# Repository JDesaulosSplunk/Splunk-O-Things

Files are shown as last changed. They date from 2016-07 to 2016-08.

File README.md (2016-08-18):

# Splunk-O-Things
Code, Schematics, and Guides for the Splunk O' Things device

## Setup
Follow GitHub's instructions here for downloading: https://help.github.com/articles/cloning-a-repository/

Add a "config.txt" to the SD card on the device.

## "config.txt"
This file is stored on the SD card on the device in the root directory.   
The four items it needs to have are: 
  1. `Port` number to send data to
  2. `Host` IP or DNS address to send data to
  3. `SSID` of the Wi-Fi network the device will connect to
  4. `Password` associated with the `SSID`

This file is formatted in the same order as above. each item is on a new line with no other formatting text.

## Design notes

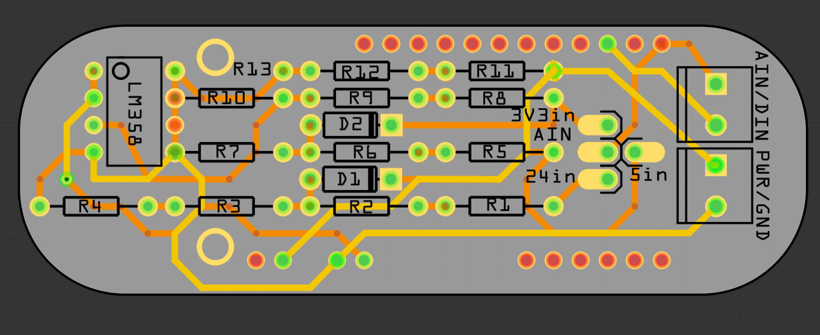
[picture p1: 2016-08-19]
Schematics:Diagrams/PCB Screen Shot.png

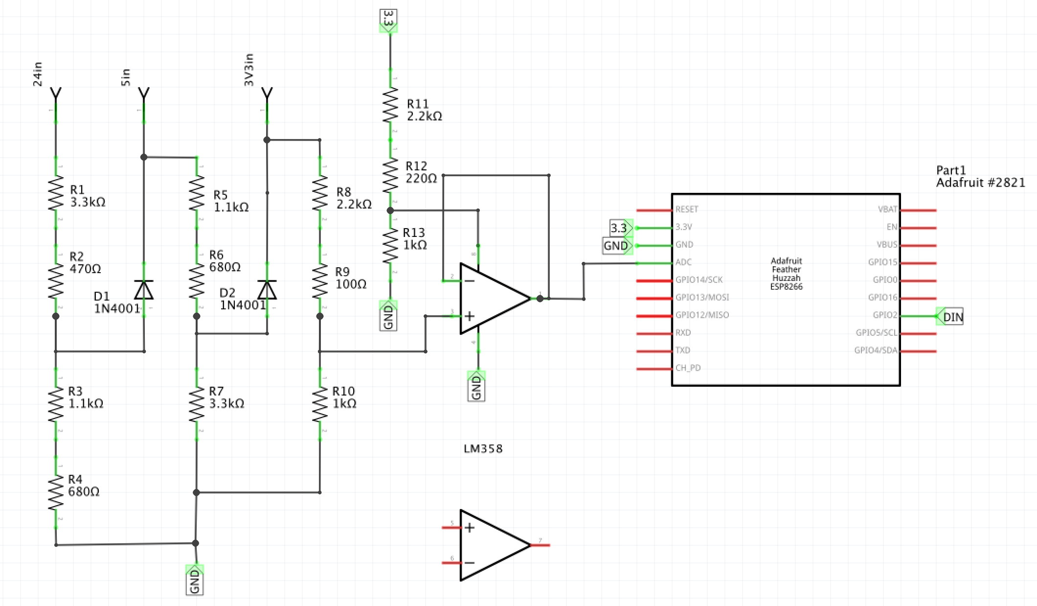
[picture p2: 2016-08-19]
Schematics:Diagrams/Analog Stepdown and Buffering Circuit.png

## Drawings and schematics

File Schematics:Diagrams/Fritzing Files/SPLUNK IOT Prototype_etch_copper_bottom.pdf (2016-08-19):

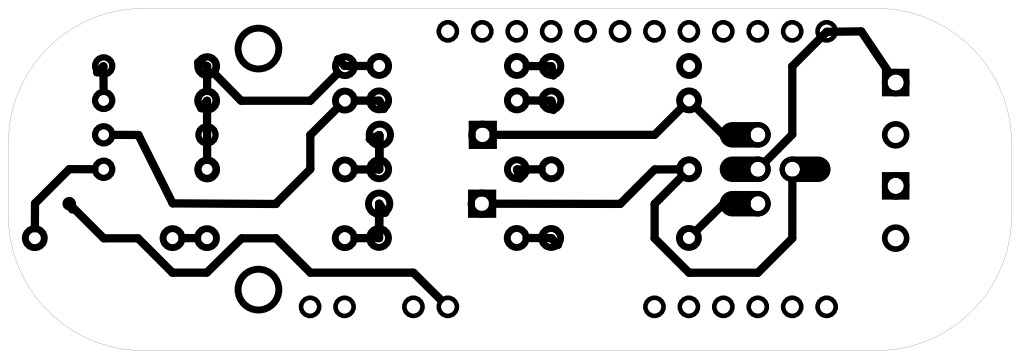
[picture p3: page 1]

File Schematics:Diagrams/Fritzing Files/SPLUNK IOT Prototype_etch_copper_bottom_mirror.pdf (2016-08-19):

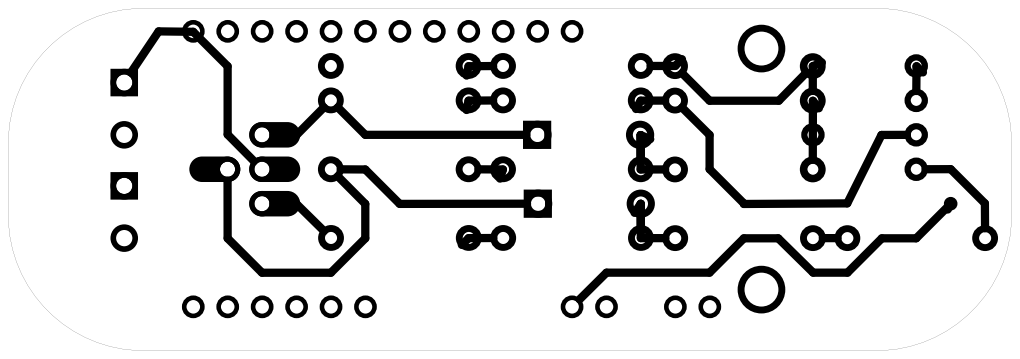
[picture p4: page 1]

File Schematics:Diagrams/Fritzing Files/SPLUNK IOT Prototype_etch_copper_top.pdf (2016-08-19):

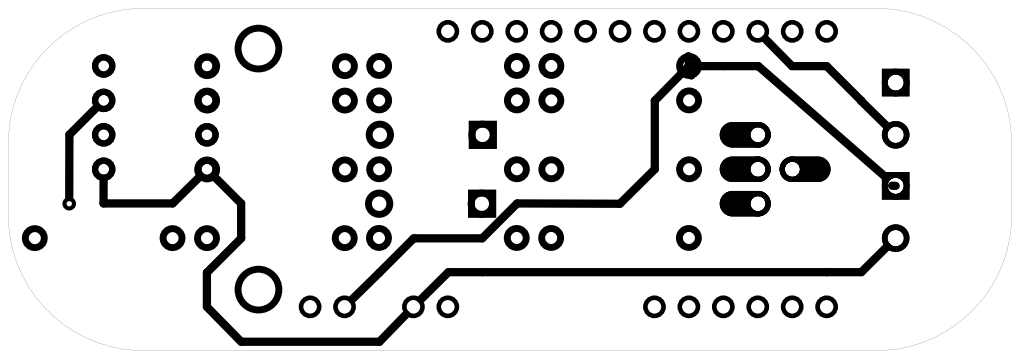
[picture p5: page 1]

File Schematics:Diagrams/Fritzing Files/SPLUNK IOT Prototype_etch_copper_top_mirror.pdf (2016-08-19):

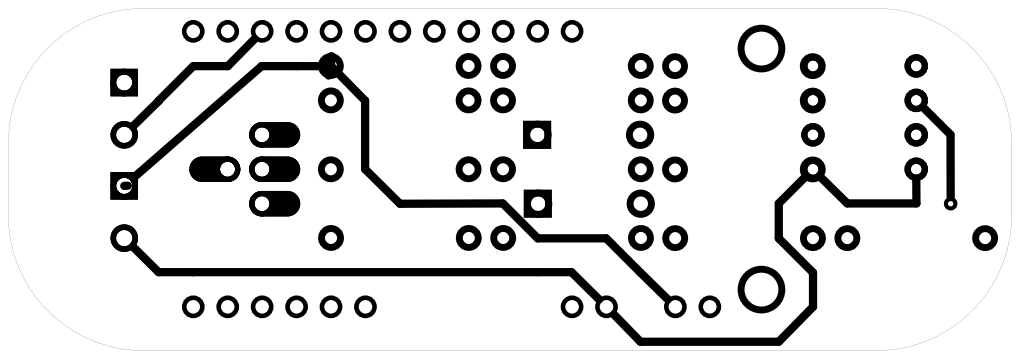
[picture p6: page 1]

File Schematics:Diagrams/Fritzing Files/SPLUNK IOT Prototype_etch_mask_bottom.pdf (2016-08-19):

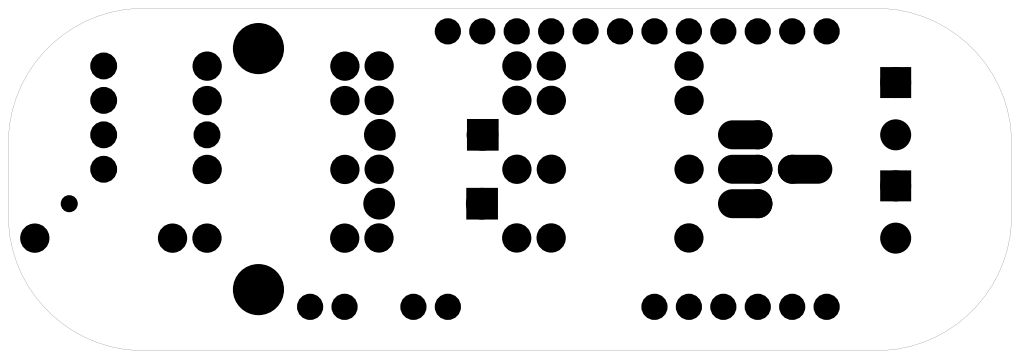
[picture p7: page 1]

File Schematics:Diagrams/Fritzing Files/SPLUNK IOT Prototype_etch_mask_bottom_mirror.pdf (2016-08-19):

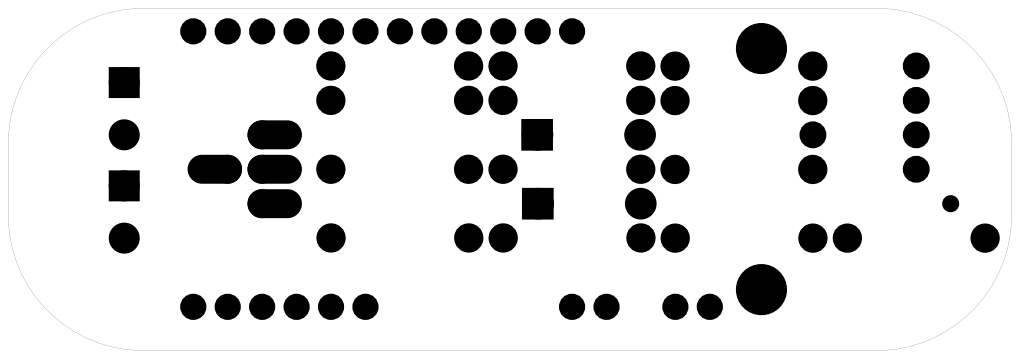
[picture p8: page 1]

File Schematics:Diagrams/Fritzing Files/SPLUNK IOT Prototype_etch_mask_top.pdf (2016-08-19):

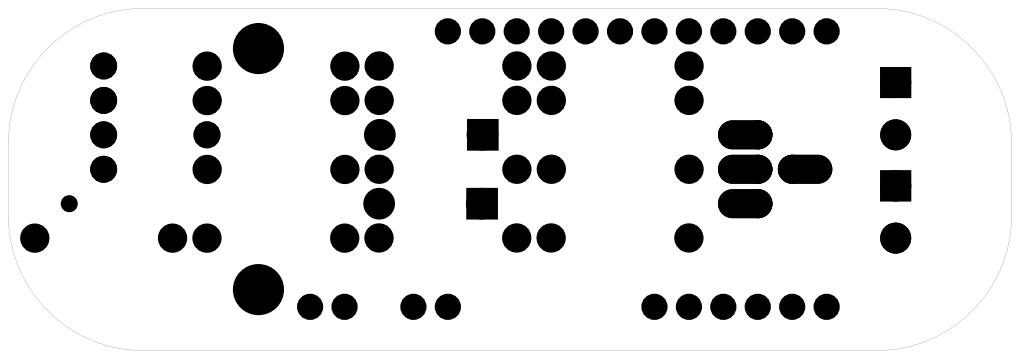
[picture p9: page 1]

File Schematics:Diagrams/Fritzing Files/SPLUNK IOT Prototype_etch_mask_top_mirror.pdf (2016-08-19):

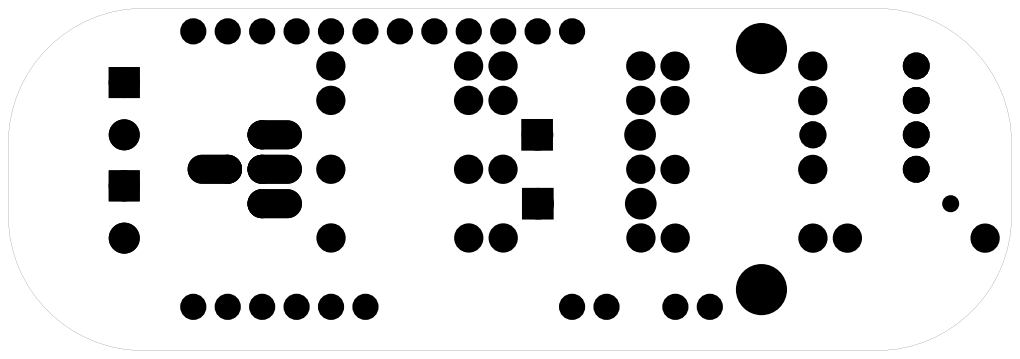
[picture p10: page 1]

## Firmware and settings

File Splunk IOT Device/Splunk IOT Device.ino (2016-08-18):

/* https://github.com/esp8266/Arduino/blob/master/libraries/ESP8266WiFi/examples/WiFiClientBasic/WiFiClientBasic.ino
 *  This sketch sends a message to a TCP server
 *
 */
// Date and time functions using a DS1307 RTC connected via I2C and Wire lib
#include <Wire.h>
#include "RTClib.h"

#if defined(ARDUINO_ARCH_SAMD)
// for Zero, output on USB Serial console, remove line below if using programming port to program the Zero!
	#define Serial SerialUSB
#endif

#include <ESP8266WiFi.h>
#include <ESP8266WiFiMulti.h>
#include "DHT.h"

#include <SPI.h>
#include <SD.h>

#include <WiFiUdp.h>
#define DHTPIN 2
#define DHTTYPE DHT11   // DHT 11
DHT dht(DHTPIN, DHTTYPE);
float f;
float h;
int pR;
char buffer[6];
// Use WiFiClient class to create TCP connections
WiFiClient client;

RTC_PCF8523 rtc;
ESP8266WiFiMulti WiFiMulti;

char daysOfTheWeek[7][12] = {"Sunday", "Monday", "Tuesday", "Wednesday", "Thursday", "Friday", "Saturday"};
TimeSpan offset = 18020;

int photocellPin = 0;     // the cell and 10K pulldown are connected to a0
int photocellReading;     // the analog reading from the sensor divider
const int chipSelect = 15;

unsigned int localPort = 2390;      // local port to listen for UDP packets
IPAddress timeServerIP; // time.nist.gov NTP server address
const char* ntpServerName = "time.nist.gov";

const int NTP_PACKET_SIZE = 48; // NTP time stamp is in the first 48 bytes of the message

byte packetBuffer[ NTP_PACKET_SIZE]; //buffer to hold incoming and outgoing packets

// A UDP instance to let us send and receive packets over UDP
WiFiUDP udp;
const uint16_t port = 2319;
const char * host = "192.168.10.227"; // ip or dns

unsigned long epoch;

String settings[4];

unsigned long sendNTPpacket(IPAddress& address) {
	Serial.println("sending NTP packet...");
	// set all bytes in the buffer to 0
	memset(packetBuffer, 0, NTP_PACKET_SIZE);
	// Initialize values needed to form NTP request
	// (see URL above for details on the packets)
	packetBuffer[0] = 0b11100011;   // LI, Version, Mode
	packetBuffer[1] = 0;     // Stratum, or type of clock
	packetBuffer[2] = 6;     // Polling Interval
	packetBuffer[3] = 0xEC;  // Peer Clock Precision
	// 8 bytes of zero for Root Delay & Root Dispersion
	packetBuffer[12]  = 49;
	packetBuffer[13]  = 0x4E;
	packetBuffer[14]  = 49;
	packetBuffer[15]  = 52;

	// all NTP fields have been given values, now
	// you can send a packet requesting a timestamp:
	udp.beginPacket(address, 123); //NTP requests are to port 123
	udp.write(packetBuffer, NTP_PACKET_SIZE);
	udp.endPacket();
}

void doUDP() {
	Serial.println("Starting UDP");
	udp.begin(localPort);
	Serial.print("Local port: ");
	Serial.println(udp.localPort());

	WiFi.hostByName(ntpServerName, timeServerIP);
	sendNTPpacket(timeServerIP); // send an NTP packet to a time server
	// wait to see if a reply is available
	delay(1000);

	int cb = udp.parsePacket();
	if (!cb)
	{
		Serial.println("no packet yet");
	}
	else
	{
		Serial.print("packet received, length=");
		Serial.println(cb);
		// We've received a packet, read the data from it
		udp.read(packetBuffer, NTP_PACKET_SIZE); // read the packet into the buffer

		//the timestamp starts at byte 40 of the received packet and is four bytes,
		// or two words, long. First, esxtract the two words:

		unsigned long highWord = word(packetBuffer[40], packetBuffer[41]);
		unsigned long lowWord = word(packetBuffer[42], packetBuffer[43]);
		// combine the four bytes (two words) into a long integer
		// this is NTP time (seconds since Jan 1 1900):
		unsigned long secsSince1900 = highWord << 16 | lowWord;
		Serial.print("Seconds since Jan 1 1900 = " );
		Serial.println(secsSince1900);

		// now convert NTP time into everyday time:
		Serial.print("Unix time = ");
		// Unix time starts on Jan 1 1970. In seconds, that's 2208988800:
		const unsigned long seventyYears = 2208988800UL;
		// subtract seventy years:
		epoch = secsSince1900 - seventyYears;
		// print Unix time:
		Serial.println(epoch);
	}
}

void getSettings(char* fileName, String *settings) {
	byte b = 0;
	if (SD.exists(fileName) == false)
	{
		Serial.println("File not found");
		return;
	}
	File myFile = SD.open(fileName, FILE_READ);
	if (!myFile)
	{
		Serial.println("Cannot open file");
		return;
	}
	myFile.seek(0);
	while (myFile.available())
	{
		settings[b] = myFile.readStringUntil('\n');
		b++;
	}
	myFile.close();
	Serial.print("Host: ");
	Serial.println(settings[0]);
	Serial.print("Port: ");
	Serial.println(settings[1]);
	Serial.print("SSID: ");
	Serial.println(settings[2]);
	Serial.print("PASS: ");
	Serial.println(settings[3]);
}

void setup() {
	#ifndef ESP8266
		while (!Serial); // for Leonardo/Micro/Zero
	#endif

	Serial.begin(115200);
	delay(10);

	Serial.print("Initializing SD card...");
	// see if the card is present and can be initialized:
	if (!SD.begin(chipSelect))
	{
		Serial.println("Card failed, or not present");
		// don't do anything more:
		return;
	}
	Serial.println("card initialized.");

//***************	 Gets wifi information from SD card.	***************
	getSettings("config.txt", settings);

	const uint16_t port2 = atoi(settings[1].c_str());
	const char * host2 = settings[0].c_str(); // ip or dns
	const char * mySSID2 = settings[2].c_str();
	const char * PASS2 = settings[3].c_str();

	Serial.println(port2);
	Serial.println(host2);
	Serial.println(mySSID2);
	Serial.println(PASS2);
//******************************************************************

	// We start by connecting to a WiFi network
	WiFiMulti.addAP(mySSID2,PASS2);

	Serial.println();
	Serial.println();
	Serial.print("Wait for WiFi... ");

	while(WiFiMulti.run() != WL_CONNECTED)
	{
		Serial.print(".");
		delay(500);
	}

	Serial.println();
	Serial.println("WiFi connected");
	Serial.println("IP address: ");
	Serial.println(WiFi.localIP());

    delay(500);

	Serial.print("connecting to ");
	Serial.println(host2);

	if (!client.connect(host2, port2))
	{
		Serial.println("connection failed");
		Serial.println("wait 5 sec...");
		delay(5000);
		return;
	}

	doUDP();

	if (! rtc.begin())
	{
		Serial.println("Couldn't find RTC");
	while (1);
	}

	if (! rtc.initialized())
	{
		Serial.println("RTC is NOT running!");
		// following line sets the RTC to the date & time this sketch was compiled
		rtc.adjust(DateTime(epoch));
	}

}

void loop() {
	const uint16_t port2 = atoi(settings[1].c_str());
	const char * host2 = settings[0].c_str(); // ip or dns

	f = dht.readTemperature(true);
	h = dht.readHumidity();
	String tf = dtostrf(f, 4, 1, buffer);
	float hif = dht.computeHeatIndex(f, h);
	pR = analogRead(photocellPin);

	DateTime now = rtc.now();
	String dataString = "{\"Time\":\"" + (String)now.unixtime() + "\",\"Temperature\":\"" + tf + "\",\"Humidity\":\"" + h + "\",\"Light\":\"" + pR + "\",\"Heat_Index\":\"" + hif + "\"}";

//***************	Send dataString over TCP to Splunk/Forwarder	***************
	if (client.connected())
	{
		client.println(dataString);
		Serial.print("Data sent over TCP: ");
		Serial.println(dataString);
	}
	else
	{
		Serial.println("Data NOT SENT OVER TCP!");
		Serial.println("Reconnecting to tcp port" + port2);

		if (!client.connect(host2, port2))
		{
			Serial.println("connection failed");
			Serial.println("wait 5 sec...");
			delay(5000);
			return;
		}
		else
		{
			Serial.println("Reconnected.");
		}
		client.println(dataString);
		Serial.print("Data sent over TCP: ");
		Serial.println(dataString);
	}

//***************	Write dataString to SD card.	***************
	File dataFile = SD.open("datalog.txt", FILE_WRITE);

	// if the file is available, write to it:
	if (dataFile)
	{
		dataFile.println(dataString);
		dataFile.close();
	}
	// if the file isn't open, pop up an error:
	else
	{
		Serial.println("error opening datalog.txt");
	}

	Serial.println("wait 3 sec...");
	delay(3000);
}

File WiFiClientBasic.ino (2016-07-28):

  /*
 *  This sketch sends a message to a TCP server
 *
 */

#include <ESP8266WiFi.h>
#include <ESP8266WiFiMulti.h>

ESP8266WiFiMulti WiFiMulti;
String temp;
void setup() {
    Serial.begin(9600);
    delay(10);

    // We start by connecting to a WiFi network
    WiFiMulti.addAP("SSID", "PASS");

    Serial.println();
    Serial.println();
    Serial.print("Wait for WiFi... ");

    while(WiFiMulti.run() != WL_CONNECTED) {
        Serial.print(".");
        delay(500);
    }

    Serial.println("");
    Serial.println("WiFi connected");
    Serial.println("IP address: ");
    Serial.println(WiFi.localIP());

    delay(500);
}


void loop() {
    const uint16_t port = 2319;
    const char * host = "192.168.10.82"; // ip or dns

    
    
    Serial.print("connecting to ");
    Serial.println(host);

    // Use WiFiClient class to create TCP connections
    WiFiClient client;

    if (!client.connect(host, port)) {
        Serial.println("connection failed");
        Serial.println("wait 5 sec...");
        delay(5000);
        return;
    }
    delay(10000);
    temp = Serial.read();
    delay(1000);
    // This will send the request to the server
    client.print(temp);
    Serial.println("3");
    Serial.println(temp);
    delay(2000);

    //read back one line from server
    String line = client.readStringUntil('\r');
    client.println(line);

    Serial.println("closing connection");
    client.stop();
    
    Serial.println("wait 5 sec...");
    delay(5000);
}

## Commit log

2016-08-04 Arduino Pro Mini Test Code
    Test code for the Arduino Pro Mini for Serial Communications with an
    ESP8266.
2016-08-04 Modification for Adafruit Feather Huzzah
    Code to send temperature data to Splunk from an Adafruit Feather
    Huzzah.
2016-08-04 Working for sending temperature data
2016-08-04 Revert "Make TCP Great Again"
    This reverts commit c1ed67d7162702d13736d6afc592f04e63c47891.
    [WiFiClientBasic.ino]
2016-08-04 Working Code with JSON Formatting addition
    Discovered that the error with unixtime not appearing in Splunk was due
    to the fact that the time was in GMT and not CST. Will need to resolve
    time zone issue
    [WiFiClientBasic.ino]
2016-08-05 Added Time Offset and SD card support
    Added functions to write the logged data to an SD card and also added a
    time offset to correct the issue created at compilation. When using the
    Adafruit RTC library, the compiler will set the time to whatever the
    time is on the computer as GMT. For example, if the time is currently
    10:30 AM CST, the library’s function for setting time will set the time
    to 10:30 AM GMT.
    [WiFiClientBasic.ino]
2016-08-09 Underscore added to string to correct "Heat Index" issue
    [WiFiClientBasic.ino]
2016-08-16 Configuration from SD Card added
    The ability to pull wifi and connection configuration from the SD card
    was added. The configuration file is named “config.txt”. The settings
    are separated by new lines.
    Line 1 is the Host IP.
    Line 2 is the TCP Port.
    Line 3 is the WIFI SSID.
    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
2016-08-18 Cleaned up code
    Fixed indentation length to 4 spaces;
    Spaces to tabs;
    // Added comments;
    Created some uniformity among the chaos of spaghetti code
    [WiFiClientBasic.ino]
2016-08-19 EOD Commit
    Addition of schematics
    [SPLUNK IOT Prototype.fzz]
